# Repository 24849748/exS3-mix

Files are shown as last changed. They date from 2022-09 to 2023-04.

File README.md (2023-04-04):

# exS3

<br>

- 为学习ESP32 S3和LVGL而设计的软硬件项目
- 尺寸迷你，包含3D外壳约40×60×18mm
- 自制4层PCB，模块剩余引脚从侧面引出，可自由扩展

<br>

## 硬件信息
>- MCU：ESP32 S3 N8R8
>- 屏幕：2.0inch ST7789 SPI接口，分辨率240×320
>- 存储：8Mb Flash + 外置SD Card
>- 输入设备：按键（GPIO0）+ 旋转编码器 + FT62x6电容触摸
>- 电池：3.7V锂电池 100mA 301525
>- 指示：LED + DET402/震动马达
>- 陀螺仪：MPU6050
>- 电源管理：AXP173

<br>

## 图片

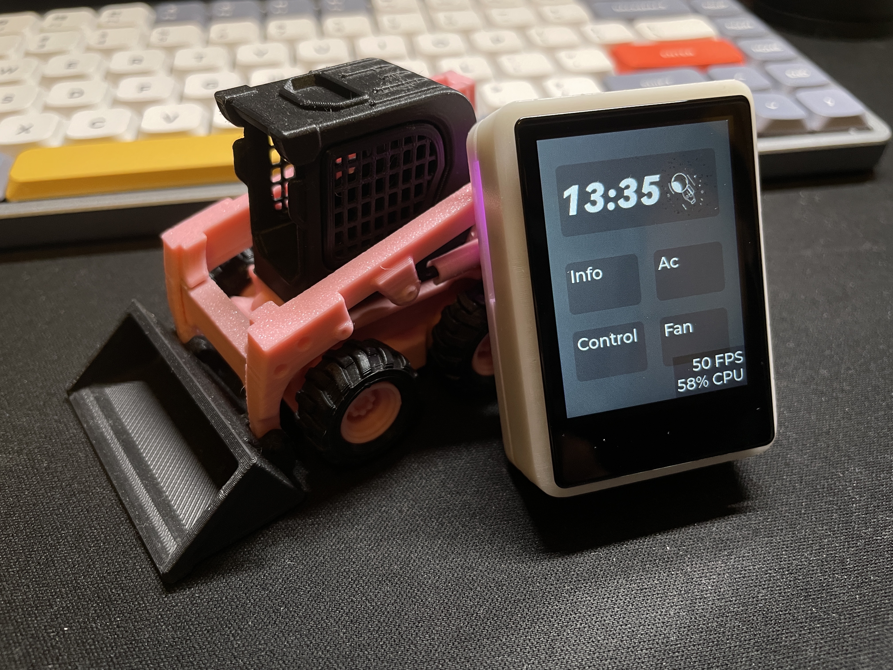
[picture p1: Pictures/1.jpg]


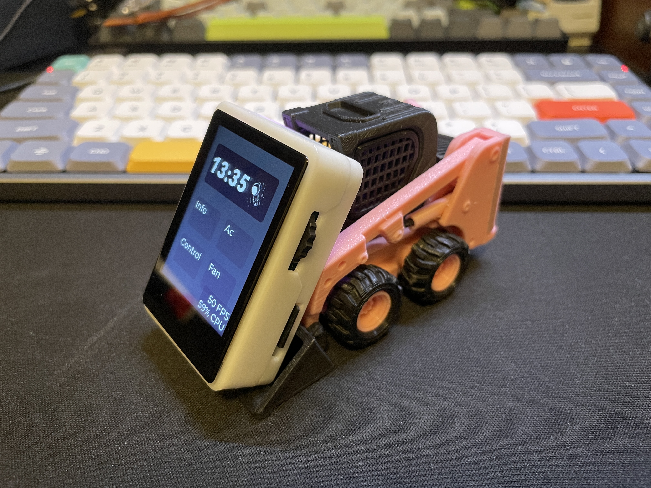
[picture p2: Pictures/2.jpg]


<br>

---

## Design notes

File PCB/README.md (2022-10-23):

### 外设引脚（exS3）

| name | gpio | name | gpio |
| --- | --- | --- | --- |
| SPI_MOSI | 10 | I2C_SDA  | 48 |
| SPI_MISO | 14 | I2C_SCL  | 47 |
| SPI_CLK  | 13 | CTP_INT  | 46 |
| TFT_CS | 12 | //// | //// |
| TFT_DC | 21 | LED | 1 |
| TFT_RST  | 11 | BUZZ | 38 |
| TFT_BLK  | 45 | //// | //// |
| SD_CS | 9 | ECD_A | 6 |
| //// | //// | ECD_B | 8 |
| PMU_IRQ  | 39 | ECD_BTN  | 15 |
| //// | //// | //// | //// |
| ~~IR_R~~ | ~~34~~ | ~~IR_T~~ | ~~26~~ |

## 硬件说明

- 正面DET402 焊盘可替换成震动马达，个人更喜欢震动马达的反馈
- 两侧引出脚位可焊接8Pin2.54单排排母，右侧旋转编码器下的排母不建议焊接，会影响编码器操作，后续找到适宜的扩展元器件再做硬件修改
- 电源模块在@Forairaaaaa的方案上进行修改，尺寸更小，但焊盘距离板边小于2mm，不符合嘉立创半孔工艺。不过硬着头皮做仍可以使用，需备注按正常工艺生产
- PCB工艺，电源模块板厚1.0mm，exS3主板1.6mm

## 焊接建议

- 使用0603元件，方便焊接
- 主要元器件建议按焊接顺序（两个FPC排座—MPU6050、TypeC插座—编码器—其他元器件）来，确保引脚密集的元件不会连锡后再用热风枪焊接其他元件

## 更新说明

- 暂无

## 硬件修改汇总

- [2022.10.23] 
  - LED需要更靠近侧边
  - AXP173的按键可以往内部收一下 / 修改按键模型
  - 在正面为电池留更多空间，热敏电阻移到相应位置

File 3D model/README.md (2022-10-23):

## **esS3 3D外壳**

> - [2022.9.21] 模型较小，使用FDM 3D打印未达到理想效果（可能是我的Ender3V2调校问题）
> - [2022.10.23] 已重新设计3D外壳，并通过三维猴树脂打印验证，底板边框需要加高1.5mm左右，或者在ESP32S3模块位置挖空，按键较小，暂未打印

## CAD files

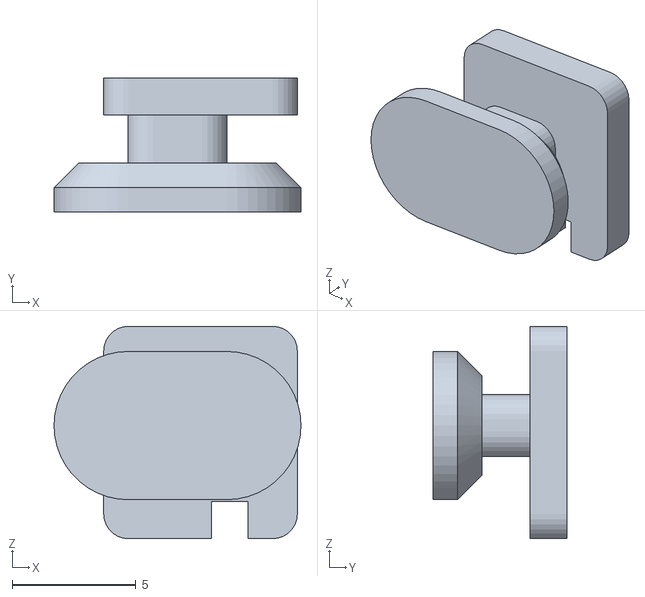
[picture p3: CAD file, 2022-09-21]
3D model/pico/switch.stl
10.0 x 5.44 x 8.60

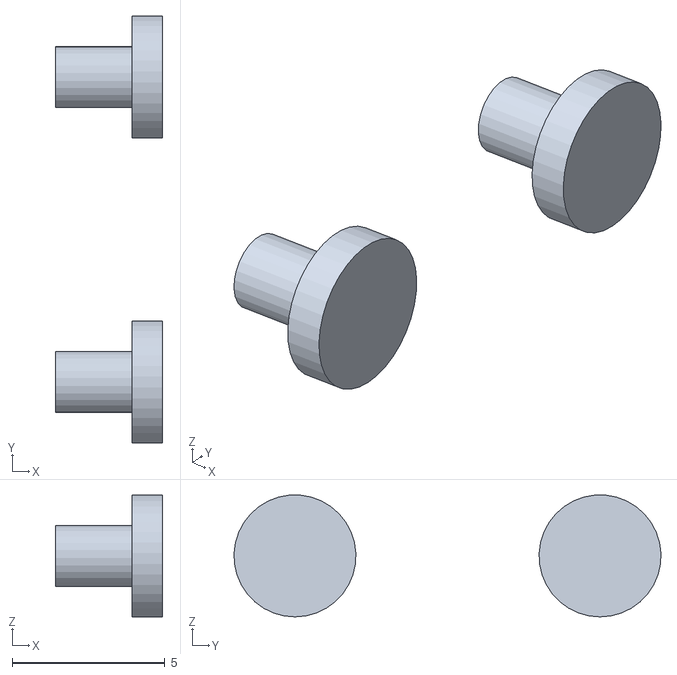
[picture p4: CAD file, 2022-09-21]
3D model/pico/key.stl
3.50 x 14.0 x 3.99

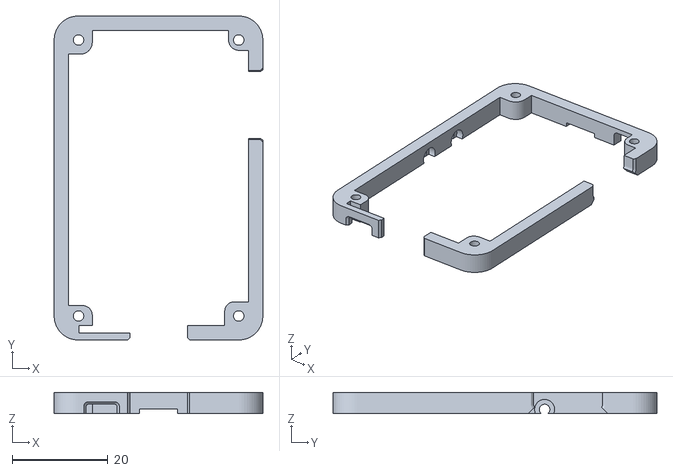
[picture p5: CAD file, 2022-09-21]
3D model/pico/middle.stl
43.7 x 67.8 x 4.50

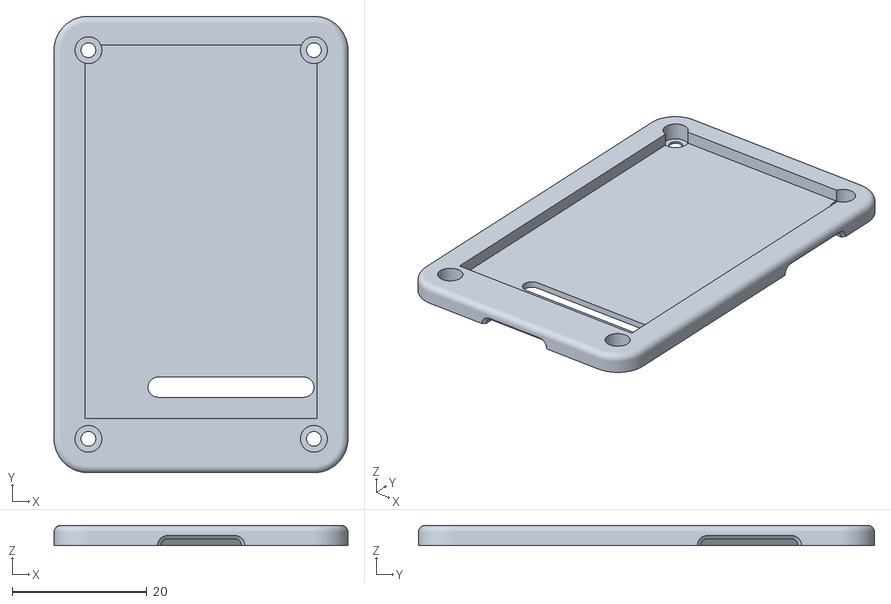
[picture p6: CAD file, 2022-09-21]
3D model/pico/top.stl
43.7 x 67.8 x 3.00

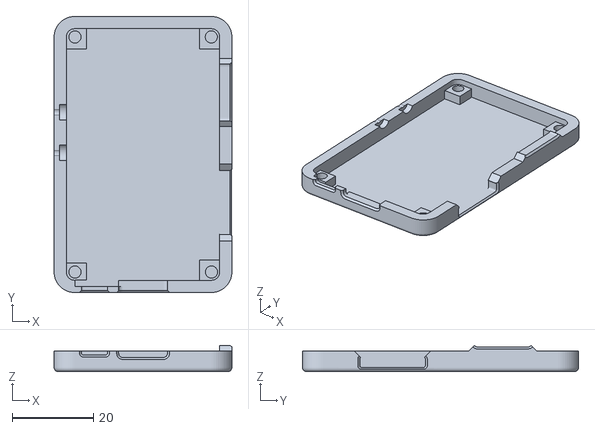
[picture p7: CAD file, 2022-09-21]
3D model/pico/bottom.stl
43.7 x 67.8 x 6.46

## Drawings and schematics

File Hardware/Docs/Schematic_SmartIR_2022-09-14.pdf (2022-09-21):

## TypeC

## USB-TTL

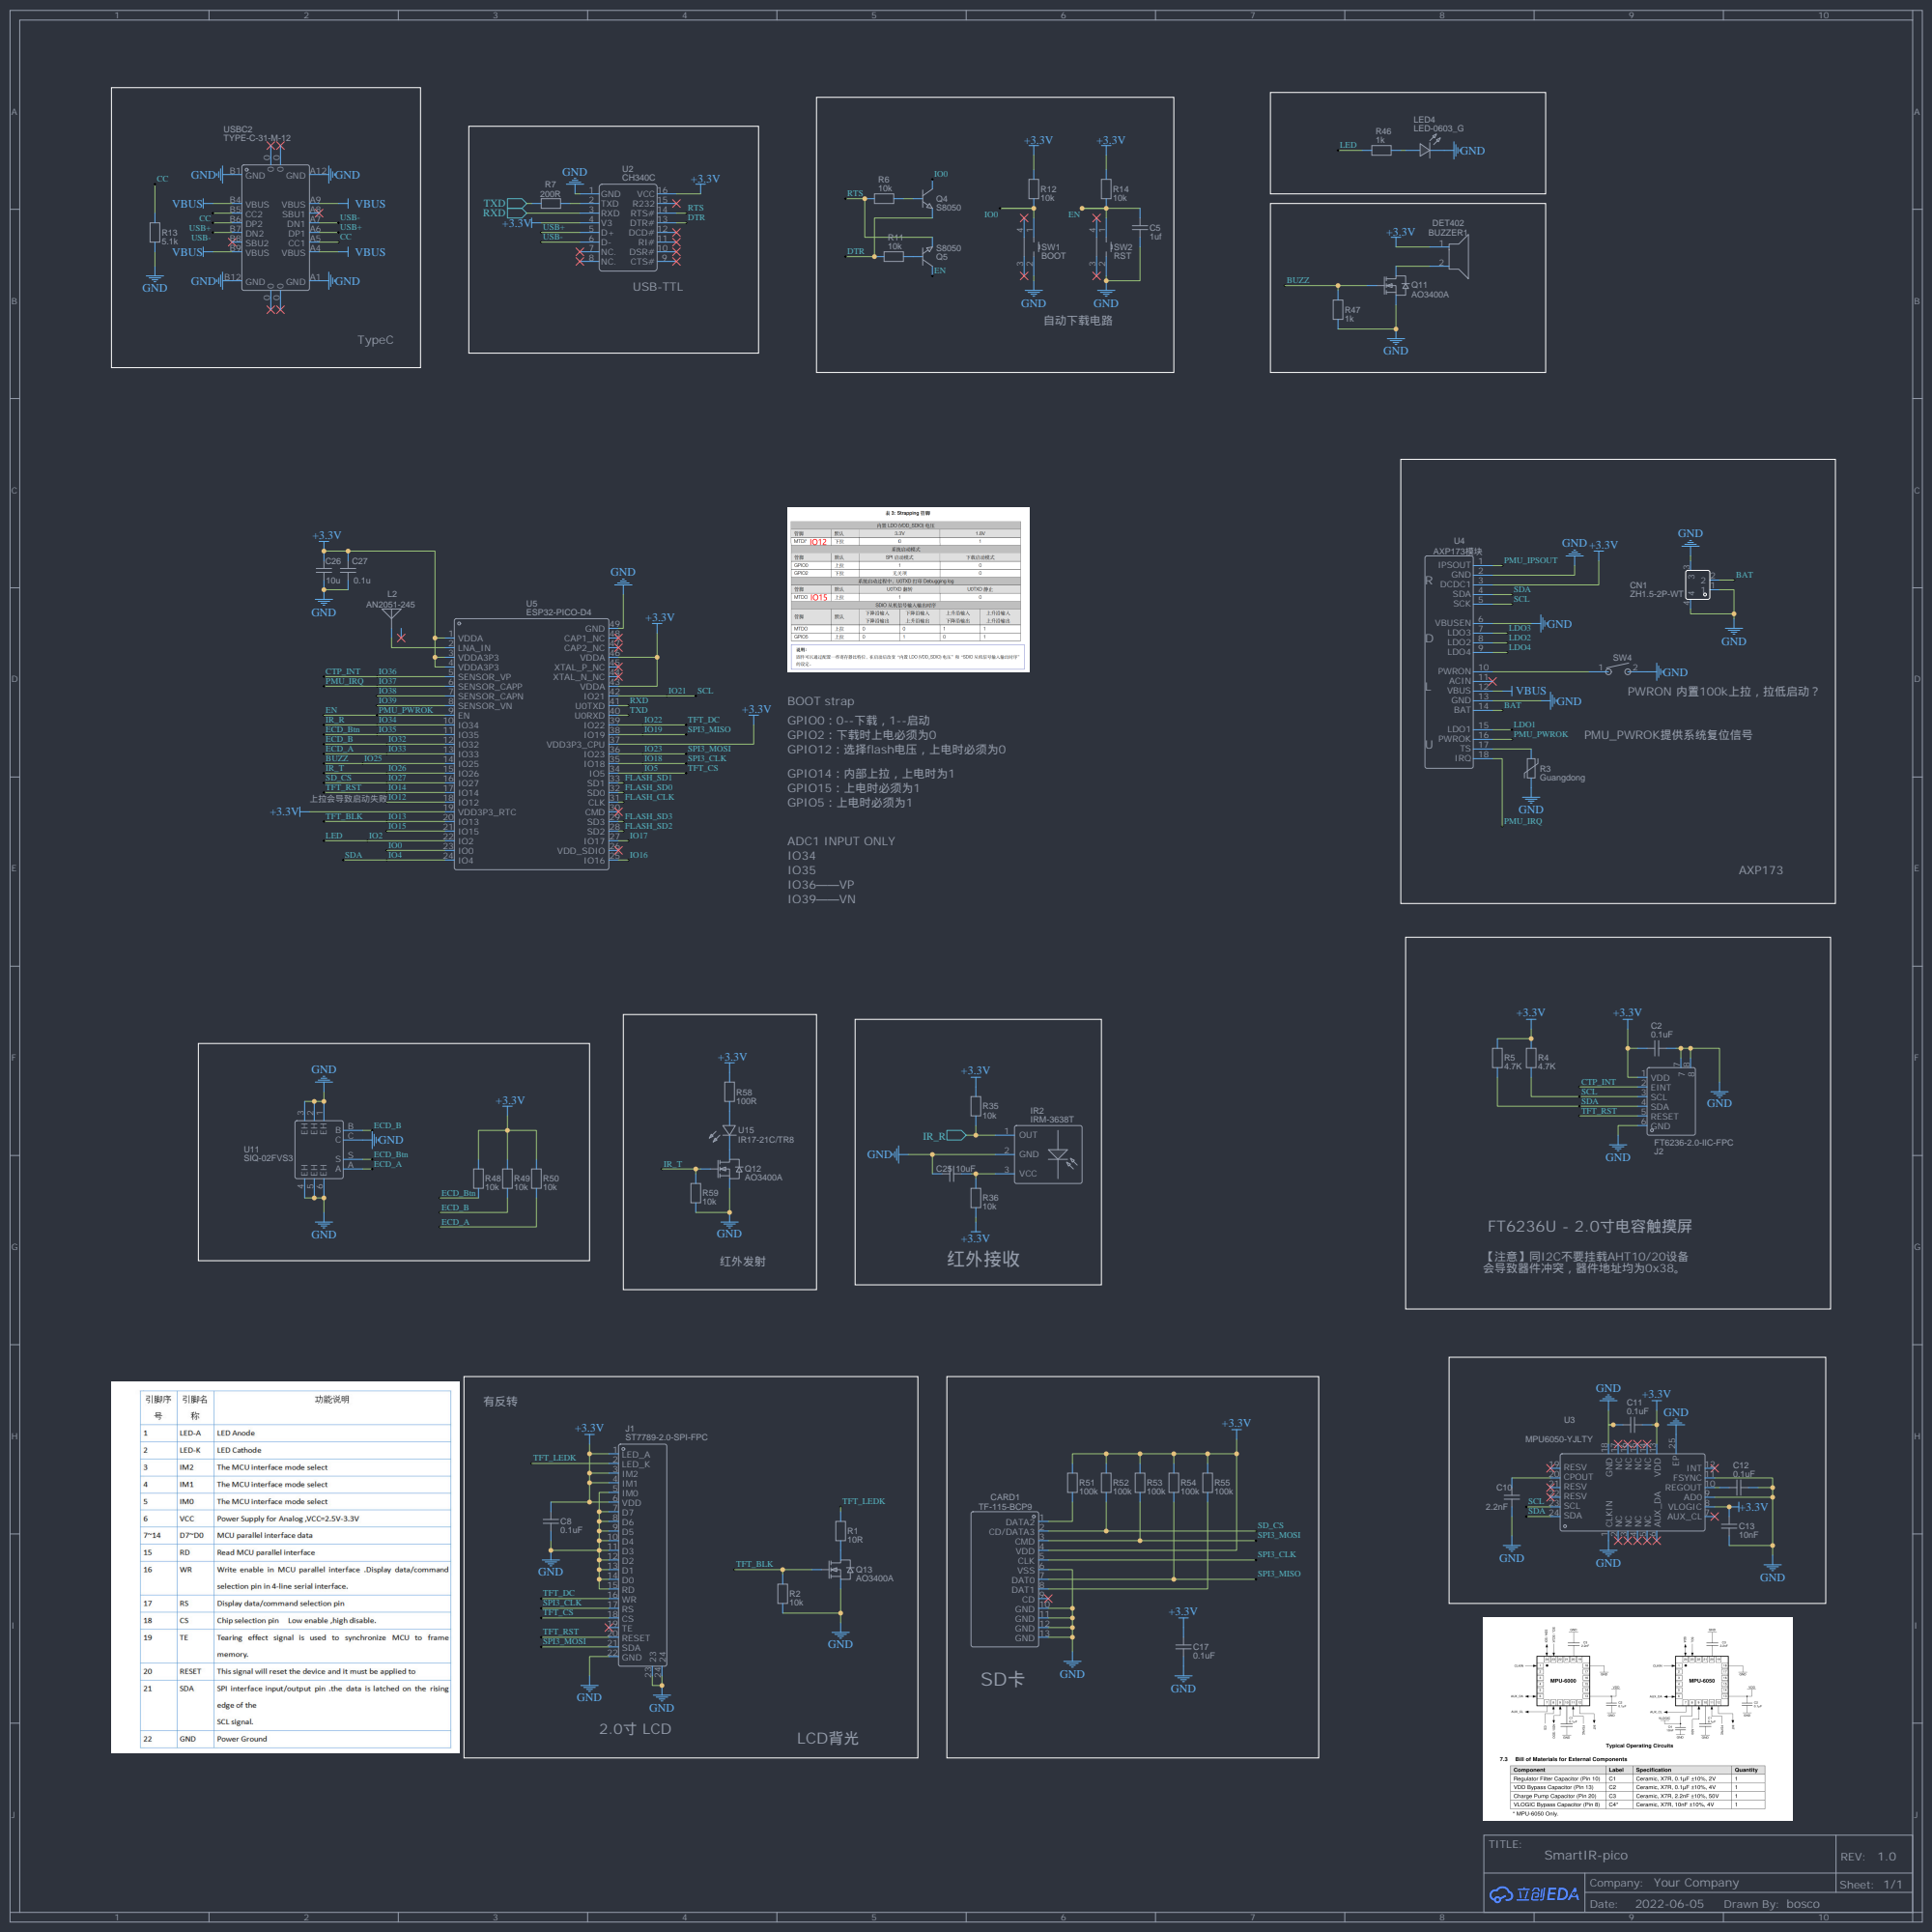
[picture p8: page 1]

VDD 13 NC 14 NC 15 NC 16 NC 17 GND 18

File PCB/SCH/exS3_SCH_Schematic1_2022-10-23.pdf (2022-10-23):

## TypeC

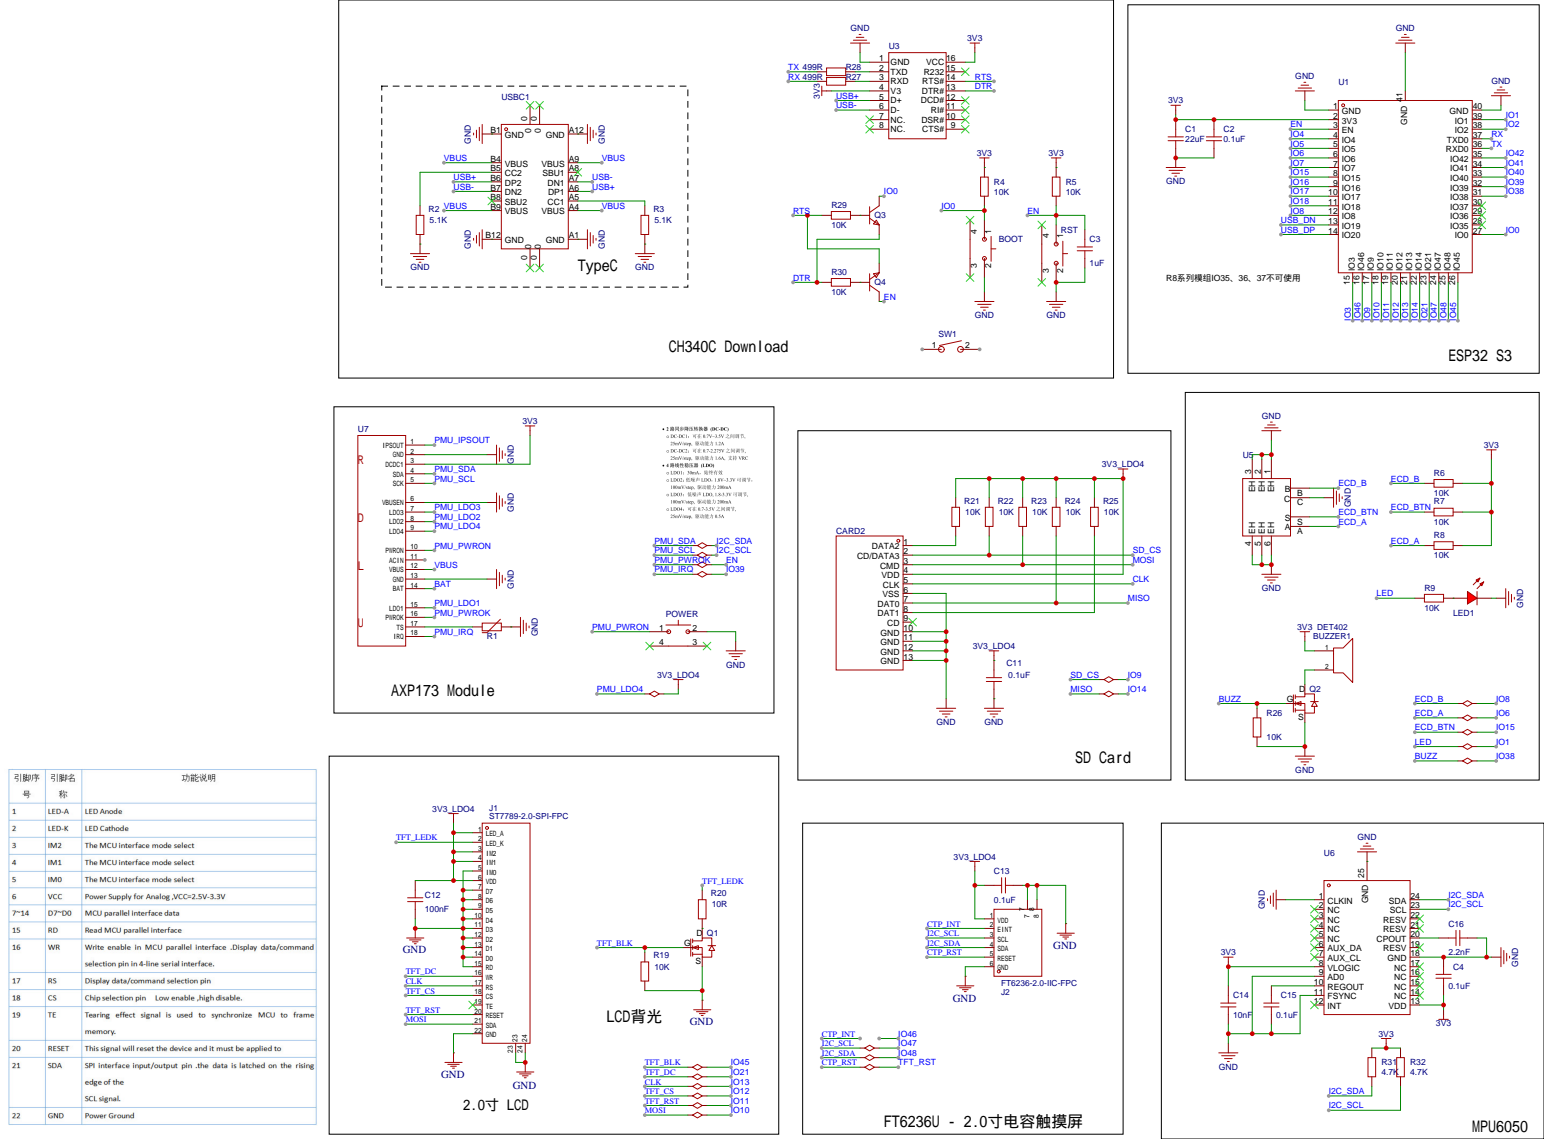
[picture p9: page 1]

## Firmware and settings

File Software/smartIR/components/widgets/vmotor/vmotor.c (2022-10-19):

#include "vmotor.h"
#include "esp_log.h"

#define TAG "vmotor"

esp_err_t vmotor_init(gpio_num_t pin, uint32_t level){
    gpio_config_t conf = {
        .intr_type = GPIO_PIN_INTR_DISABLE,
        .mode = GPIO_MODE_INPUT_OUTPUT,
        .pin_bit_mask = (1ULL << pin),
        .pull_down_en = 0,
        .pull_up_en = 0,
    };
    esp_err_t ret = gpio_config(&conf);
    if(ret != ESP_OK){
        ESP_LOGE(TAG, "vmotor configurate failed!");
        return ESP_FAIL;
    }

    ret = gpio_set_level(pin, level);
    if(ret!=ESP_OK){
        ESP_LOGE(TAG, "vmotor set failed!");
        return ESP_FAIL;
    }
    return ESP_OK;
}

void vmotor_blink(gpio_num_t pin){
    uint8_t level = gpio_get_level(pin);
    gpio_set_level(pin, !level);
}

void vmotor_on(gpio_num_t pin){
    gpio_set_level(pin, 1);
}
void vmotor_off(gpio_num_t pin){
    gpio_set_level(pin, 0);
}

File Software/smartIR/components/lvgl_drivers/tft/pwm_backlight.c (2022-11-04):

#include "pwm_backlight.h"

#include "driver/gpio.h"
#include "driver/ledc.h"
#include "soc/ledc_periph.h"
#include <stdio.h>
#include "esp_log.h"

#define TAG "pwm_backlight"

typedef struct {
    bool pwm_control; // true: LEDC is used, false: GPIO is used
    int index;        // Either GPIO or LEDC channel
} pwm_backlight_t;


pwm_backlight_handle_t pwm_backlight_create(const pwm_backlight_config_t *config){
    if(config == NULL) return NULL;
    if(!GPIO_IS_VALID_OUTPUT_GPIO(config->gpio_num)){
        ESP_LOGW(TAG, "Invalid GPIO");
        return NULL;
    }

    pwm_backlight_t * bl_dev = calloc(1,sizeof(pwm_backlight_t));
    if(bl_dev == NULL){
        ESP_LOGW(TAG, "calloc backlight dev filed");
        return NULL;
    }

    if(config->pwm_control){
        bl_dev->pwm_control = true;
        bl_dev->index = config->channel_idx;
        const ledc_channel_config_t LCD_backlight_channel = {
            .gpio_num = config->gpio_num,
            .speed_mode = LEDC_LOW_SPEED_MODE,
            .channel = config->channel_idx,
            .intr_type = LEDC_INTR_DISABLE,
            .timer_sel = config->timer_idx,
            .duty = 0,
            .hpoint = 0
        };
        const ledc_timer_config_t LCD_backlight_timer = {
            .speed_mode = LEDC_LOW_SPEED_MODE,
            .bit_num = LEDC_TIMER_10_BIT,
            .timer_num = config->timer_idx,
            .freq_hz = 5000,
            .clk_cfg = LEDC_AUTO_CLK};

        ESP_ERROR_CHECK(ledc_timer_config(&LCD_backlight_timer));
        ESP_ERROR_CHECK(ledc_channel_config(&LCD_backlight_channel));
        gpio_matrix_out(config->gpio_num, ledc_periph_signal[LEDC_LOW_SPEED_MODE].sig_out0_idx + config->channel_idx, config->output_invert, 0);
    }else {
        bl_dev->index = config->gpio_num;
        gpio_pad_select_gpio(config->gpio_num);
        ESP_ERROR_CHECK(gpio_set_direction(config->gpio_num, GPIO_MODE_OUTPUT));
        gpio_matrix_out(config->gpio_num, SIG_GPIO_OUT_IDX, config->output_invert, false);
    }

    return (pwm_backlight_handle_t)bl_dev;
}

void pwm_backlight_set(pwm_backlight_handle_t bl, int brightness_percent){
    if(bl == NULL) return;
    if(brightness_percent > 100) brightness_percent = 100;
    if(brightness_percent < 0) brightness_percent = 0;

    pwm_backlight_t *bl_dev = (pwm_backlight_t *) bl;
    ESP_LOGI(TAG, "Setting LCD backlight: %d%%", brightness_percent);

    if(bl_dev->pwm_control){
        uint32_t duty_cycle = (1023 * brightness_percent) / 100; // LEDC resolution set to 10bits, thus: 100% = 1023
        ESP_ERROR_CHECK(ledc_set_duty(LEDC_LOW_SPEED_MODE, bl_dev->index, duty_cycle));
        ESP_ERROR_CHECK(ledc_update_duty(LEDC_LOW_SPEED_MODE, bl_dev->index));
    }else {
        ESP_ERROR_CHECK(gpio_set_level(bl_dev->index, brightness_percent));
    }
}

void pwm_backlight_delete(pwm_backlight_handle_t bl)
{
    if (bl == NULL) return;

    pwm_backlight_t *bckl_dev = (pwm_backlight_t *) bl;
    if (bckl_dev->pwm_control) {
        ledc_stop(LEDC_LOW_SPEED_MODE, bckl_dev->index, 0);
    } else {
        gpio_reset_pin(bckl_dev->index);
    }
    free (bl);
}

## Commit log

2022-10-16 add pcb 3d model
    [3D_exS3.step]
2022-10-23 使用新版UI
2022-10-23 修改目录结构
    [3D_exS3.step, bottom.stl, key.stl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]
2022-10-25 移除encoder相关组件
2022-10-25 ui控制led和motor
2022-10-27 modify axp173 driver
2022-10-29 修改、验证部分读取数据的函数
2022-10-29 修改info_page的AXP173显示
2022-10-31 添加axp173中断功能，未做测试
2022-11-04 修改官方的背光驱动，未测试应用
2022-11-05 添加wifi和sntp获取时间，但未成功，先备份
2022-11-05 修改屏幕驱动，梳理程序框架和启动流程
2022-11-06 使用freertos定时器添加震动反馈
2022-11-07 震动反馈支持自定义震动时长
2022-11-07 单独添加nvs文件,修改sdcard文件
2022-11-07 添加当前工程Kconfig文件,暂未在具体文件中include
2022-11-08 添加encoder调节LCD背光功能
2022-11-10 将原来encoder_button组件独立出来，后续将支持多按键
2022-11-10 添加息屏led闪烁指示
2022-11-10 修复息屏能触摸操作的bug
2022-11-12 添加开机加载界面
2022-11-18 去除不透明度动画，ui更流畅；添加liner动画
2022-11-18 添加gui任务句柄，以使用任务通知设置亮度
2022-11-19 修复开机动画bug，资源顺利回收
2022-11-19 添加lvgl屏幕亮度调节组件
